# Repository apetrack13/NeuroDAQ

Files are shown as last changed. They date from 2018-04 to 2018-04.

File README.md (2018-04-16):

# NeuroDAQ
<p> The NeuroDAQ is a quality control device for transcranial electrical stimulation (tES) generation devices.
The aim is to improve the outcomes of tES studies by verifying the fidelity of stimulation generation from
tES devices. </p>
<h2>Setting Up the NeuroDAQ</h2>
<p> The NeuroDAQ requires a connection to a local network. </p>

<h3>Setup Wireless Connection</h3>

1.)	Check if micro USB power cable is connected to NeuroDAQ located on the side.

2.)	Remove micro SD card from NeuroDAQ located on the side. 

3.)	Insert micro SD card into adaptor SD card adaptor provided with kit.

4.)	Plug the SD Card adaptor into computer. A new volume should appear in your finder/ file explorer.

5.)	Open the new volume and navigate to the boot directory /Volumes/boot.

6.)	Create a file called wpa_supplicant.conf in this directory and save it.

7.)	Open the file and add the following details:                                                					network={												ssid=”YOUR_NETWORK_NAME”									psk=”YOUR_PASSWORD”									key_mgmt=WPA-PSK

8.)	Eject the SD card and plug it back into the NeuroDAQ.

<h2>Using the NeuroDAQ via Terminal</h2>
<h3>Establish SSH Connection to NeuroDAQ</h3>
<p>
The NeuroDAQ can be controlled via a ssh connection. Once a ssh connection is established, data acquisition can be iniated.
</p>
1.)	First, be sure the micro USB power cable is connected to the NeuroDAQ.

2.)	Open terminal in the applications folder of Mac OS computer.

3.)	Type ssh pi@NeuroDAQ.local and press enter.

4.)	If prompted to answer a yes or no question, type yes and press enter. If not, skip to step 4.

5.)	You will be prompted to enter a password to connect to the device. The password is “GIZMO629” (obviously no quotes).

6.)	You are now connected to the device’s terminal from which you can execute scripts.

<h3>Retrieve Data File</h3>
1.)	In the Mac OS terminal connected to the device, type and enter:					scp pi@NeuroDAQ.local:~/Desktop/DATA_FILE_NAME.csv ~/Desktop		

Replace DATA_FILE_NAME with what you named the data file during data acquisition. 

2.)	The data file will be transferred to the desktop of your Mac OS computer. You now can process this data file with the MATLAB script provided.

<h3>Process Data File with MATLAB</h3>
1.)	Locate the MATLAB script file named “Process_Signal.m”. This script is available at github.com/NeuroModQC-WSU-Design/NeuroDAQ/.

2.)	Place the data file in the same directory as this script.

3.)	Open the script with MATLAB and run.

4.)	You will be prompted to answer questions about the stimulation paradigm recorded. Please, refer to the stimulation paradigm parameters used to record the data file.

5.)	Statistical analysis and graphs of stimulation paradigm will be presented.

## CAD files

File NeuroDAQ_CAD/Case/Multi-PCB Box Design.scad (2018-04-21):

/*//////////////////////////////////////////////////////////////////                
////////////////////////////////////////////////////////////////////                                                                                                           


*/////////////////////////// - Info - //////////////////////////////

// All coordinates are starting as integrated circuit pins.
// From the top view :

//   CoordD           <---       CoordC
//                                 ^
//                                 ^
//                                 ^
//   CoordA           --->       CoordB


////////////////////////////////////////////////////////////////////


////////// -  Box parameters - /////////////

/* [Box dimensions] */
// - Length  
  Length        = 254;       
// - Width
  Width         = 200;                     
// - Height  
  Height        = 100;  
// - Wall thickness  
  Thick         = 2;//[2:5]  
  
/* [Box options] */
// - Filet diameter  
  Filet         = 2;//[0.1:12] 
// - Filet smoothness  
  Resolution    = 50;//[1:100] 
// - Tolerance (Panel/rails gap)
  m             = 0.9;
// - PCB feet (x4) 
  PCBFeet       = 1;// [0:No, 1:Yes]
// - PCB2 feet (x4) 
  PCB2Feet       = 1;// [0:No, 1:Yes] 
// - PCB3 feet (x4) 
  PCB3Feet       = 1;// [0:No, 1:Yes] 
// - PCB4 feet (x4) 
  PCB4Feet       = 1;// [0:No, 1:Yes] 
// - PCB5 feet (x4) 
  PCB5Feet       = 0;// [0:No, 1:Yes]
// - PCB6 feet (x4)
  PCB6Feet       = 1;// [0:No, 1:Yes]  
// - Ventilation Holes
  Vent          = 1;// [0:No, 1:Yes]
// - Holes width (in mm)
  Vent_width    = 1.5;   


  
/* [PCB_Feet - Raspberry Pi] */
//All dimensions are from the center foot axis

// - Low left corner X position
PCBPosX         = 180;
// - Low left corner Y position
PCBPosY         = 84;
// - PCB Length
PCBLength       = 49;
// - PCB Width
PCBWidth        = 58;
// - Feet height
FootHeight      = 10;
// - Foot diameter
FootDia         = 8;
// - Hole diameter
FootHole        = 3;  


/* [PCB2_Feet - Purple PCB] */
//All dimensions are from the center foot axis

// - Low left corner X position
PCB2PosX         = 7;
// - Low left corner Y position
PCB2PosY         = 116;
// - PCB2 Length
PCB2Length       = 63;
// - PCB Width
PCB2Width        = 54;
// - Feet height
Foot2Height      = 10;
// - Foot diameter
Foot2Dia         = 8;
// - Hole diameter
Foot2Hole       = 3; 


/* [PCB3_Feet - Green PCB 1 - Connected to Green PCB 2] */
//All dimensions are from the center foot axis

// - Low left corner X position
PCB3PosX         = 120;
// - Low left corner Y position
PCB3PosY         = 116;
// - PCB2 Length
PCB3Length       = 35;
// - PCB Width
PCB3Width        = 55;
// - Feet height
Foot3Height      = 10;
// - Foot diameter
Foot3Dia         = 8;
// - Hole diameter
Foot3Hole       = 3;

/* [PCB4_Feet - Green PCB 2 - Connected to Green PCB 1] */
//All dimensions are from the center foot axis

// - Low left corner X position
PCB4PosX         = 120;
// - Low left corner Y position
PCB4PosY         = 10;
// - PCB2 Length
PCB4Length       = 35;
// - PCB Width
PCB4Width        = 55;
// - Feet height
Foot4Height      = 10;
// - Foot diameter
Foot4Dia         = 8;
// - Hole diameter
Foot4Hole       = 3;

/* [PCB5_Feet - Green PCB 3] */
//All dimensions are from the center foot axis

// - Low left corner X position
PCB5PosX         = 60;
// - Low left corner Y position
PCB5PosY         = 10;
// - PCB2 Length
PCB5Length       = 35;
// - PCB Width
PCB5Width        = 55;
// - Feet height
Foot5Height      = 10;
// - Foot diameter
Foot5Dia         = 8;
// - Hole diameter
Foot5Hole       = 3;

/* [PCB6_Feet - Green PCB 1 - Connected to Green PCB 2] */
//All dimensions are from the center foot axis

// - Low left corner X position
PCB6PosX         = 5;
// - Low left corner Y position
PCB6PosY         = 10;
// - PCB2 Length
PCB6Length       = 35;
// - PCB Width
PCB6Width        = 55;
// - Feet height
Foot6Height      = 10;
// - Foot diameter
Foot6Dia         = 8;
// - Hole diameter
Foot6Hole       = 3;
  

/* [STL element to export] */
// - Top shell
TShell          = 0;// [0:No, 1:Yes]
// - Bottom shell
BShell          = 1;// [0:No, 1:Yes]
// - Front panel
FPanL           = 1;// [0:No, 1:Yes]
// - Back panel  
BPanL           = 1;// [0:No, 1:Yes]


  
/* [Hidden] */
// - Shell color  
Couleur1        = "Orange";       
// - Panels color    
Couleur2        = "OrangeRed";    
// Thick X 2 - make thicker; if it is a vent, want to make sure they go through shell
Dec_Thick       = Vent ? Thick*2 : Thick; 
// - Depth 
Dec_size        = Vent ? Thick*2 : 0.8;





/////////// - Generic rounded box - //////////

module RoundBox($a=Length, $b=Width, $c=Height){// Cube bords arrondis
                    $fn=Resolution;            
                    translate([0,Filet,Filet]){  
                    minkowski (){                                              
                        cube ([$a-(Length/2),$b-(2*Filet),$c-(2*Filet)], center = false);
                        rotate([0,90,0]){    
                        cylinder(r=Filet,h=Length/2, center = false);
                            } 
                        }
                    }
                }// End of RoundBox Module

      
////////////////////////////////// - Module Shell - //////////////////////////////////         

module Coque(){//Shell  
    Thick = Thick*2;  
    difference(){    
        difference(){//sides decoration
            union(){    
                     difference() {//Substraction Fileted box
                      
                        difference(){//Median cube slicer
                            union() {//union               
                            difference(){//Coque    
                                RoundBox();
                                translate([Thick/2,Thick/2,Thick/2]){     
                                        RoundBox($a=Length-Thick, $b=Width-Thick, $c=Height-Thick);
                                        }
                                        }//Fin diff Coque                            
                                difference(){//larger Rails        
                                     translate([Thick+m,Thick/2,Thick/2]){// Rails
                                          RoundBox($a=Length-((2*Thick)+(2*m)), $b=Width-Thick, $c=Height-(Thick*2));
                                                          }//fin Rails
                                     translate([((Thick+m/2)*1.55),Thick/2,Thick/2+0.1]){ // +0.1 added to avoid the artefact
                                          RoundBox($a=Length-((Thick*3)+2*m), $b=Width-Thick, $c=Height-Thick);
                                                    }           
                                                }//Fin largeur Rails
                                    }//Fin union                                   
                               translate([-Thick,-Thick,Height/2]){// Cube à soustraire
                                    cube ([Length+100, Width+100, Height], center=false);
                                            }                                            
                                      }//End Median cube slicer
                               translate([-Thick/2,Thick,Thick]){ 
                                    RoundBox($a=Length+Thick, $b=Width-Thick*2, $c=Height-Thick);       
                                    }                          
                                }                                          


                difference(){// wall fixation box legs
                    union(){
                        translate([3*Thick +5,Thick,Height/2]){
                            rotate([90,0,0]){
                                    $fn=6;
                                    cylinder(d=16,Thick/2);
                                    }   
                            }
                            
                       translate([Length-((3*Thick)+5),Thick,Height/2]){
                            rotate([90,0,0]){
                                    $fn=6;
                                    cylinder(d=16,Thick/2);
                                    }   
                            }

                        }
                            translate([4,Thick+Filet,Height/2-57]){   
                             rotate([45,0,0]){
                                   cube([Length,40,40]);    
                                  }
                           }
                           translate([0,-(Thick*1.46),Height/2]){
                                cube([Length,Thick*2,10]);
                           }
                    } //Fin fixation box legs
            }

        union(){// outbox sides decorations
            
            for(i=[0:Thick:Length/4]){
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

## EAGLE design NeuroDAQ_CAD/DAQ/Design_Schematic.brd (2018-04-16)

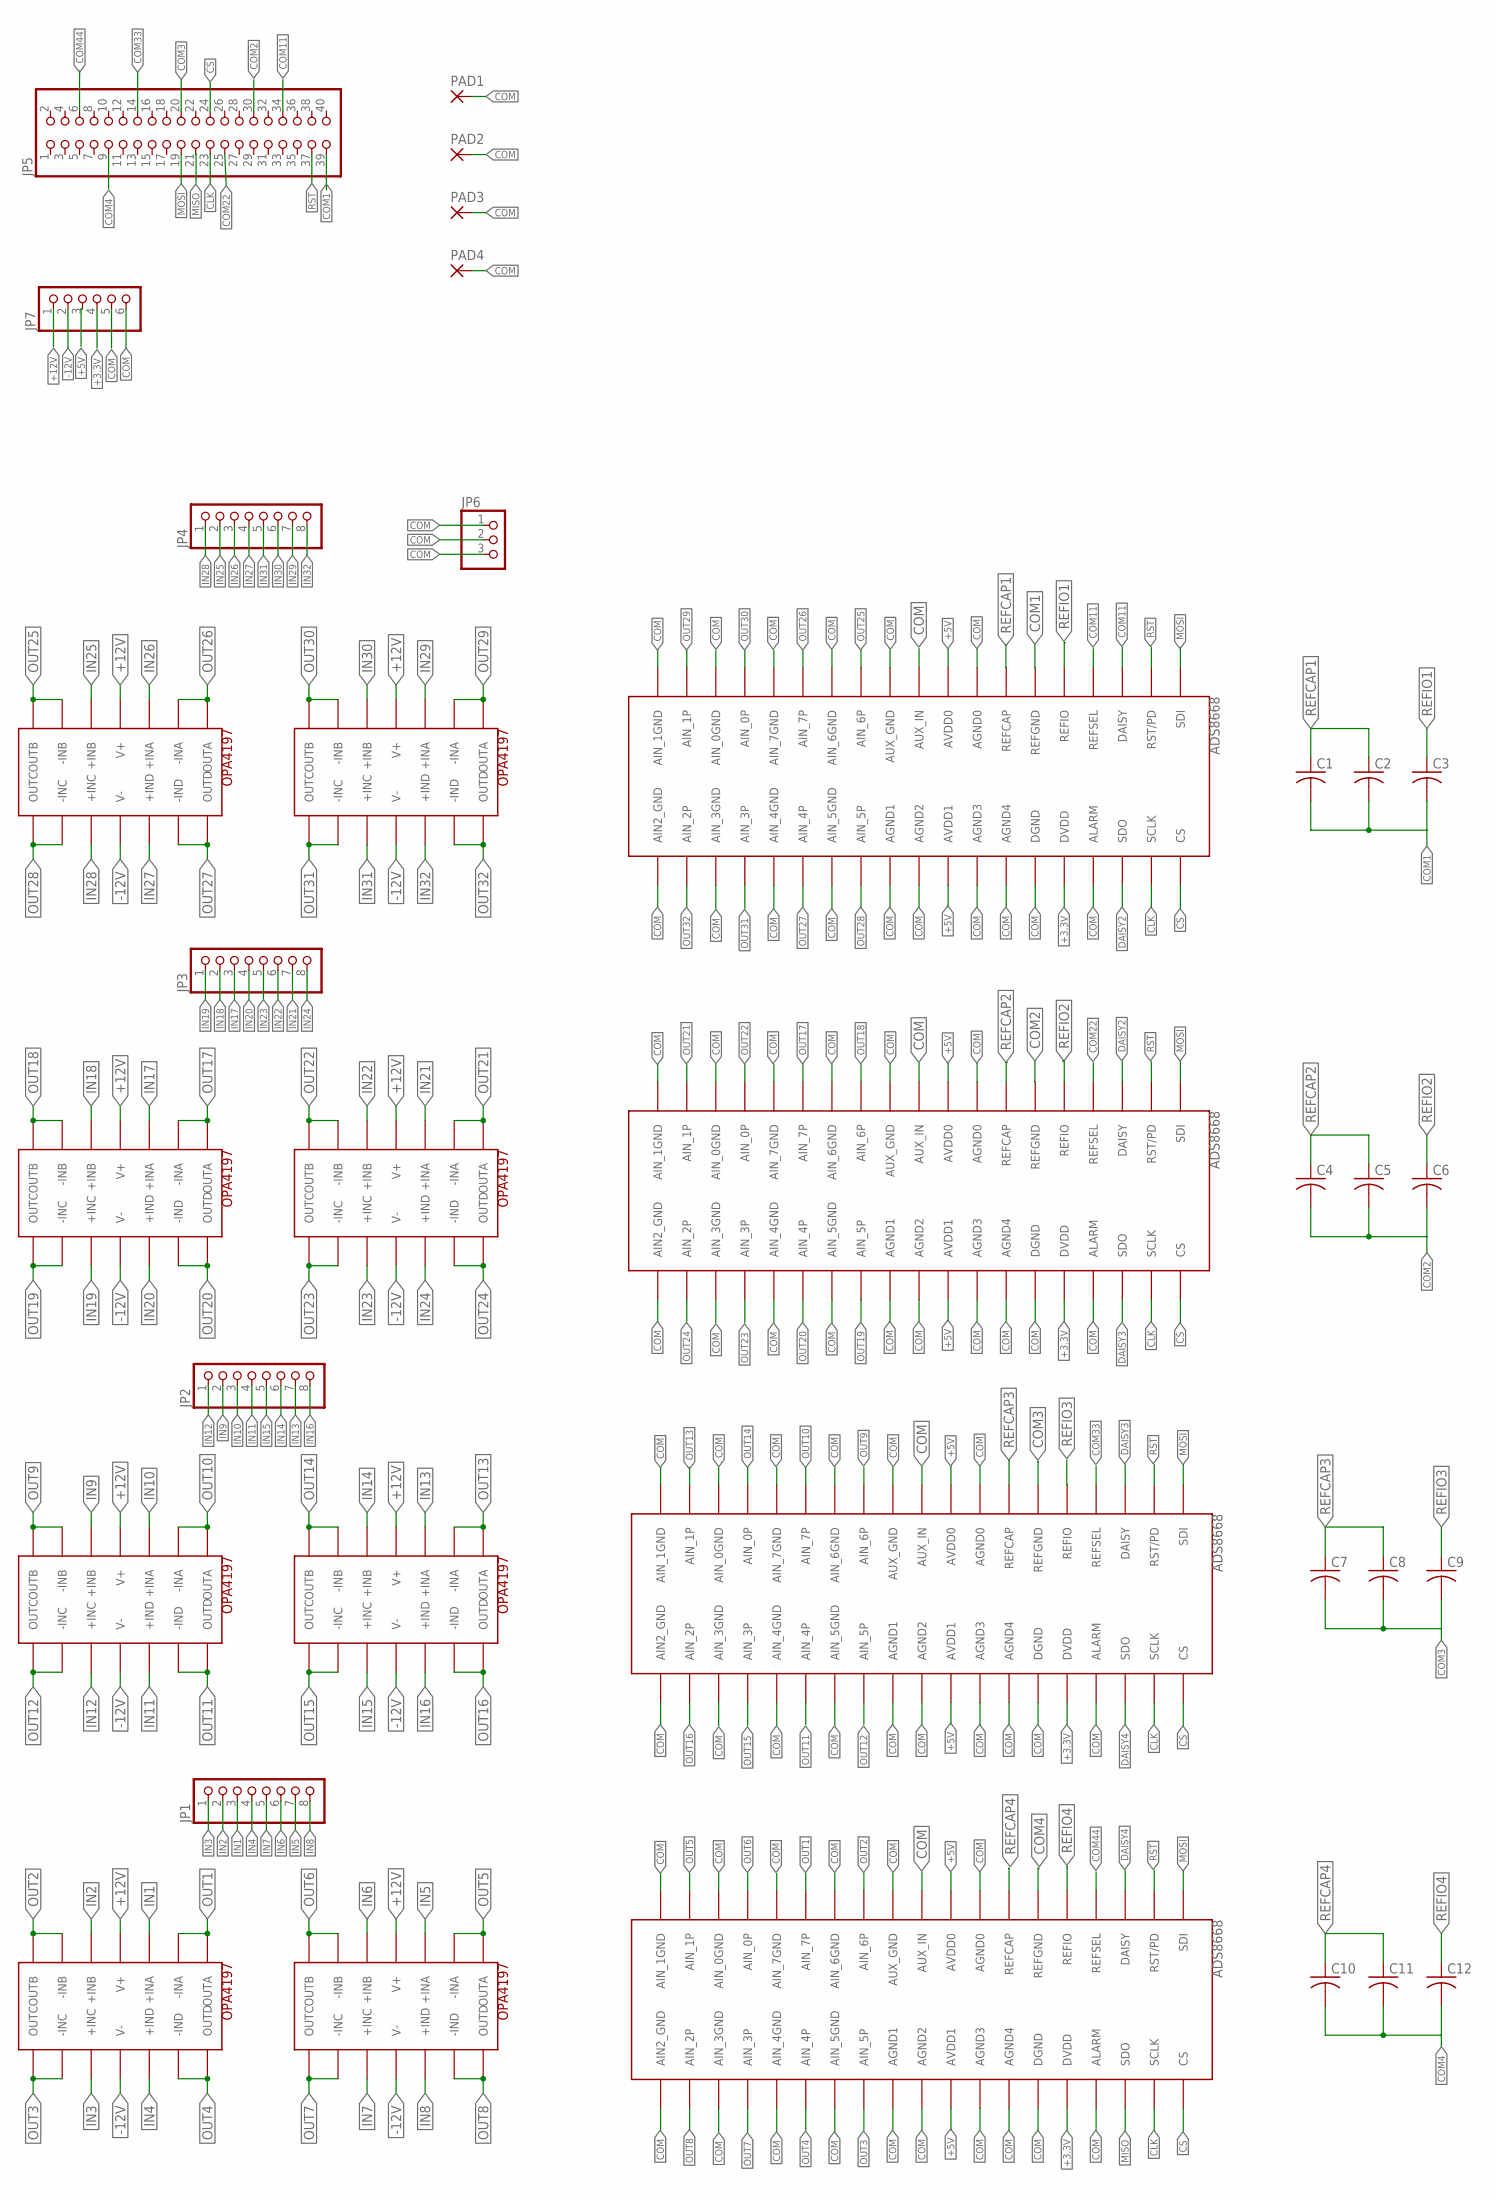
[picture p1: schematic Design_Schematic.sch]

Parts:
ADC1, ADC2, ADC3, ADC4: ADS8668
C1, C2, C3, C4, C5, C6, C7, C8, C9, C10, C11, C12: C-US025-030X050; C025-030X050
JP1, JP2, JP3, JP4: PINHD-1X8CLEANBIG; 1X08-CLEANBIG
JP5: PINHD-2X20; 2X20
JP6: PINHD-1X3; 1X03
JP7: PINHD-1X6; 1X06
PAD1, PAD2, PAD3, PAD4: 3,17/1,3
U$1, U$2, U$3, U$4, U$5, U$6, U$7, U$8: OPA4197

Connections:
+3.3V: ADC1.DVDD, ADC2.DVDD, ADC3.DVDD, ADC4.DVDD, JP7.4
+5V: ADC1.AVDD0, ADC1.AVDD1, ADC2.AVDD0, ADC2.AVDD1, ADC3.AVDD0, ADC3.AVDD1, ADC4.AVDD0, ADC4.AVDD1, JP7.3
+12V: JP7.1, U$1.V+, U$2.V+, U$3.V+, U$4.V+, U$5.V+, U$6.V+, U$7.V+, U$8.V+
-12V: JP7.2, U$1.V-, U$2.V-, U$3.V-, U$4.V-, U$5.V-, U$6.V-, U$7.V-, U$8.V-
CLK: ADC1.SCLK, ADC2.SCLK, ADC3.SCLK, ADC4.SCLK, JP5.23
COM: ADC1.AGND0, ADC1.AGND1, ADC1.AGND2, ADC1.AGND3, ADC1.AGND4, ADC1.AIN2_GND, ADC1.AIN6_GND (AIN_6GND), ADC1.AIN_0GND, ADC1.AIN_1GND, ADC1.AIN_3GND, ADC1.AIN_4GND, ADC1.AIN_5GND, ADC1.AIN_7GND, ADC1.ALARM, ADC1.AUX_GND, ADC1.AUX_IN, ADC1.DGND, ADC2.AGND0, ADC2.AGND1, ADC2.AGND2, ADC2.AGND3, ADC2.AGND4, ADC2.AIN2_GND, ADC2.AIN6_GND (AIN_6GND), ADC2.AIN_0GND, ADC2.AIN_1GND, ADC2.AIN_3GND, ADC2.AIN_4GND, ADC2.AIN_5GND, ADC2.AIN_7GND, ADC2.ALARM, ADC2.AUX_GND, ADC2.AUX_IN, ADC2.DGND, ADC3.AGND0, ADC3.AGND1, ADC3.AGND2, ADC3.AGND3, ADC3.AGND4, ADC3.AIN2_GND, ADC3.AIN6_GND (AIN_6GND), ADC3.AIN_0GND, ADC3.AIN_1GND, ADC3.AIN_3GND, ADC3.AIN_4GND, ADC3.AIN_5GND, ADC3.AIN_7GND, ADC3.ALARM, ADC3.AUX_GND, ADC3.AUX_IN, ADC3.DGND, ADC4.AGND0, ADC4.AGND1, ADC4.AGND2, ADC4.AGND3, ADC4.AGND4, ADC4.AIN2_GND, ADC4.AIN6_GND (AIN_6GND), ADC4.AIN_0GND, ADC4.AIN_1GND, ADC4.AIN_3GND, ADC4.AIN_4GND, ADC4.AIN_5GND, ADC4.AIN_7GND, ADC4.ALARM, ADC4.AUX_GND, ADC4.AUX_IN, ADC4.DGND, JP6.1, JP6.2, JP6.3, JP7.5, JP7.6, PAD1.1, PAD2.1, PAD3.1, PAD4.1
COM1: ADC4.REFGND, C1.2, C2.2, C3.2, JP5.39
COM2: ADC1.REFGND, C4.2, C5.2, C6.2, JP5.30
COM3: ADC2.REFGND, C7.2, C8.2, C9.2, JP5.20
COM4: ADC3.REFGND, C10.2, C11.2, C12.2, JP5.9
COM11: ADC4.DAISY, ADC4.REFSEL, JP5.34
COM22: ADC1.REFSEL, JP5.25
COM33: ADC2.REFSEL, JP5.14
COM44: ADC3.REFSEL, JP5.6
CS: ADC1.CS, ADC2.CS, ADC3.CS, ADC4.CS, JP5.24
DAISY2: ADC1.DAISY, ADC4.SDO
DAISY3: ADC1.SDO, ADC2.DAISY
DAISY4: ADC2.SDO, ADC3.DAISY
IN1: JP1.3, U$5.+INA
IN2: JP1.2, U$5.+INB
IN3: JP1.1, U$5.+INC
IN4: JP1.4, U$5.+IND
IN5: JP1.7, U$1.+INA
IN6: JP1.6, U$1.+INB
IN7: JP1.5, U$1.+INC
IN8: JP1.8, U$1.+IND
IN9: JP2.2, U$2.+INB
IN10: JP2.3, U$2.+INA
IN11: JP2.4, U$2.+IND
IN12: JP2.1, U$2.+INC
IN13: JP2.7, U$3.+INA
IN14: JP2.6, U$3.+INB
IN15: JP2.5, U$3.+INC
IN16: JP2.8, U$3.+IND
IN17: JP3.3, U$4.+INA
IN18: JP3.2, U$4.+INB
IN19: JP3.1, U$4.+INC
IN20: JP3.4, U$4.+IND
IN21: JP3.7, U$6.+INA
IN22: JP3.6, U$6.+INB
IN23: JP3.5, U$6.+INC
IN24: JP3.8, U$6.+IND
IN25: JP4.2, U$7.+INB
IN26: JP4.3, U$7.+INA
IN27: JP4.4, U$7.+IND
IN28: JP4.1, U$7.+INC
IN29: JP4.7, U$8.+INA
IN30: JP4.6, U$8.+INB
IN31: JP4.5, U$8.+INC
IN32: JP4.8, U$8.+IND
MISO: ADC3.SDO, JP5.21
MOSI: ADC1.SDI, ADC2.SDI, ADC3.SDI, ADC4.SDI, JP5.19
OUT1: ADC3.AIN_7P, U$5.-INA, U$5.OUTA
OUT2: ADC3.AIN_6P, U$5.-INB, U$5.OUTB
OUT3: ADC3.AIN_5P, U$5.-INC, U$5.OUTC
OUT4: ADC3.AIN_4P, U$5.-IND, U$5.OUTD
OUT5: ADC3.AIN_1P, U$1.-INA, U$1.OUTA
OUT6: ADC3.AIN_0P, U$1.-INB, U$1.OUTB
OUT7: ADC3.AIN_3P, U$1.-INC, U$1.OUTC
OUT8: ADC3.AIN_2P, U$1.-IND, U$1.OUTD
OUT9: ADC2.AIN_6P, U$2.-INB, U$2.OUTB
OUT10: ADC2.AIN_7P, U$2.-INA, U$2.OUTA
OUT11: ADC2.AIN_4P, U$2.-IND, U$2.OUTD
OUT12: ADC2.AIN_5P, U$2.-INC, U$2.OUTC
OUT13: ADC2.AIN_1P, U$3.-INA, U$3.OUTA
OUT14: ADC2.AIN_0P, U$3.-INB, U$3.OUTB
OUT15: ADC2.AIN_3P, U$3.-INC, U$3.OUTC
OUT16: ADC2.AIN_2P, U$3.-IND, U$3.OUTD
OUT17: ADC1.AIN_7P, U$4.-INA, U$4.OUTA
OUT18: ADC1.AIN_6P, U$4.-INB, U$4.OUTB
OUT19: ADC1.AIN_5P, U$4.-INC, U$4.OUTC
OUT20: ADC1.AIN_4P, U$4.-IND, U$4.OUTD
OUT21: ADC1.AIN_1P, U$6.-INA, U$6.OUTA
OUT22: ADC1.AIN_0P, U$6.-INB, U$6.OUTB
OUT23: ADC1.AIN_3P, U$6.-INC, U$6.OUTC
OUT24: ADC1.AIN_2P, U$6.-IND, U$6.OUTD
OUT25: ADC4.AIN_6P, U$7.-INB, U$7.OUTB
OUT26: ADC4.AIN_7P, U$7.-INA, U$7.OUTA
OUT27: ADC4.AIN_4P, U$7.-IND, U$7.OUTD
OUT28: ADC4.AIN_5P, U$7.-INC, U$7.OUTC
OUT29: ADC4.AIN_1P, U$8.-INA, U$8.OUTA
OUT30: ADC4.AIN_0P, U$8.-INB, U$8.OUTB
OUT31: ADC4.AIN_3P, U$8.-INC, U$8.OUTC
OUT32: ADC4.AIN_2P, U$8.-IND, U$8.OUTD
REFCAP1: ADC4.REFCAP, C1.1, C2.1
REFCAP2: ADC1.REFCAP, C4.1, C5.1
REFCAP3: ADC2.REFCAP, C7.1, C8.1
REFCAP4: ADC3.REFCAP, C10.1, C11.1
REFIO1: ADC4.REFIO, C3.1
REFIO2: ADC1.REFIO, C6.1
REFIO3: ADC2.REFIO, C9.1
REFIO4: ADC3.REFIO, C12.1
RST: ADC1.RST/PD, ADC2.RST/PD, ADC3.RST/PD, ADC4.RST/PD, JP5.37

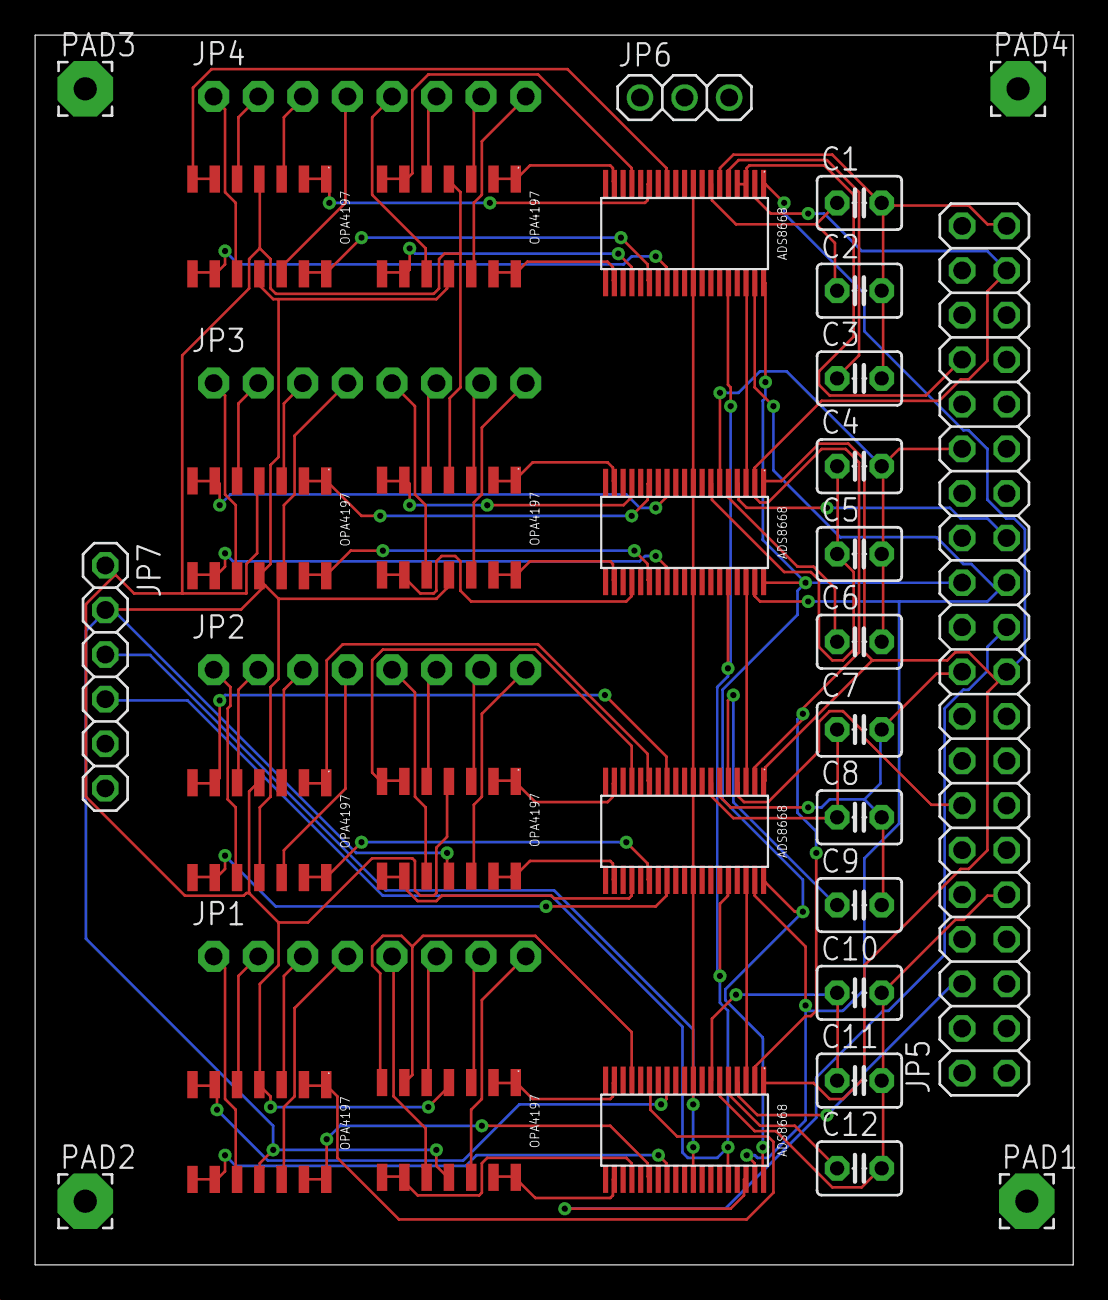
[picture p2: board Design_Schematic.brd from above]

Board: 2 copper layers, 59.1 x 70.1 mm, 35 parts (0 on the bottom side), 93 nets.

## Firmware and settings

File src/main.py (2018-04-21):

import dataAcq
import cmd

def main():
    fileName = input("Enter the name of file in double quotes: ")
    fileName = fileName + ".csv"
    duration = input("Enter duration of test in seconds: ")
    numChannels = input("Enter active number of channels: ")
    
    dataAcq.beginAcq(numChannels, duration, fileName)

main()

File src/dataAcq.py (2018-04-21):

import time
import Adafruit_GPIO.SPI as SPI
import Adafruit_MCP3008
import RPi.GPIO as gpio


def beginAcq(numChannels, duration, fileName):
    SPI_PORT = 0
    SPI_DEVICE = 0
    mcp = Adafruit_MCP3008.MCP3008(spi=SPI.SpiDev(SPI_PORT, SPI_DEVICE))

    gpio.setmode(gpio.BCM)
    gpio.setup(26, gpio.OUT)
    gpio.output(26, gpio.LOW)
    gpio.output(26, gpio.HIGH)

    t1 = time.time() + duration
    # print(t1)
    with open(fileName, 'w+') as f:
        f.write('')

    print('Reading ADS8668 values, press Ctrl-C to quit...')

    # Main Loop
    while (time.time() < t1):
        values = []
        tempTime = [0]
        tempTime[0] = round(time.time() - t1 + duration, 4)

        if numChannels == 1:
           # Channel 1
            mcp.read_all_ch(0xC0)
            values0 = mcp.read_all_ch(0xC0)
            values0[0] = ((float(values0[0]) - 2046) / 197)   # ADC 1
            values0[1] = ((float(values0[1]) - 2046) / 197)   # ADC 2

            # Append samples to array
            values.extend(values0[0:2])
            values.extend(tempTime)

        elif (numChannels == 2):
            # Channel 1
            mcp.read_all_ch(0xC0)
            values0 = mcp.read_all_ch(0xC0)
            values0[0] = ((float(values0[0]) - 2046) / 197)  # ADC 1
            values0[1] = ((float(values0[1]) - 2046) / 197)  # ADC 2
            # Channel 2
            values0[2] = ((float(values0[2]) - 2046) / 197)  # ADC 3
            values0[3] = ((float(values0[3]) - 1535) / 195)  # ADC 4

            # Append samples to array
            values.extend(values0)
            values.extend(tempTime)

        elif numChannels == 3:
            # Channel 1
            mcp.read_all_ch(0xC0)
            values0 = mcp.read_all_ch(0xC0)
            values0[0] = ((float(values0[0]) - 2046) / 197)  # ADC 1
            values0[1] = ((float(values0[1]) - 2046) / 197)  # ADC 2
            # Channel 2
            values0[2] = ((float(values0[2]) - 2046) / 197)  # ADC 3
            values0[3] = ((float(values0[3]) - 1535) / 195)  # ADC 4
            # Channel 3
            mcp.read_all_ch(0xC4)
            values1 = mcp.read_all_ch(0xC4)
            values1[0] = ((float(values1[0]) - 2046) / 200)
            values1[1] = ((float(values1[1]) - 2046) / 200)
            # Append Samples to array
            values.extend(values0)
            values.extend(values1[0:2])
            values.extend(tempTime)

        elif numChannels == 4:
            # Channel 1
            mcp.read_all_ch(0xC0)
            values0 = mcp.read_all_ch(0xC0)
            values0[0] = ((float(values0[0]) - 2046) / 197)  # ADC 1
            values0[1] = ((float(values0[1]) - 2046) / 197)  # ADC 2
            # Channel 2
            values0[2] = ((float(values0[2]) - 2046) / 197)  # ADC 3
            values0[3] = ((float(values0[3]) - 1535) / 195)  # ADC 4
            # Channel 3
            mcp.read_all_ch(0xC4)
            values1 = mcp.read_all_ch(0xC4)
            values1[0] = ((float(values1[0]) - 2046) / 200)
            values1[1] = ((float(values1[1]) - 2046) / 200)
            # Channel 4
            values1[2] = ((float(values1[2]) - 1535) / 200)
            values1[3] = ((float(values1[3]) - 1535) / 200)
            # Append Samples to array
            values.extend(values0)
            values.extend(values1)
            values.extend(tempTime)

        elif numChannels == 5:
            # Channel 1
            mcp.read_all_ch(0xC0)
            values0 = mcp.read_all_ch(0xC0)
            values0[0] = ((float(values0[0]) - 2046) / 197)  # ADC 1
            values0[1] = ((float(values0[1]) - 2046) / 197)  # ADC 2
            # Channel 2
            values0[2] = ((float(values0[2]) - 2046) / 197)  # ADC 3
            values0[3] = ((float(values0[3]) - 1535) / 195)  # ADC 4
            # Channel 3
            mcp.read_all_ch(0xC4)
            values1 = mcp.read_all_ch(0xC4)
            values1[0] = ((float(values1[0]) - 2046) / 200)
            values1[1] = ((float(values1[1]) - 2046) / 200)
            # Channel 4
            values1[2] = ((float(values1[2]) - 1535) / 200)
            values1[3] = ((float(values1[3]) - 1535) / 200)
            # Channel 5
            mcp.read_all_ch(0xC8)
            values2 = mcp.read_all_ch(0xC4)
            values2[0] = ((float(values2[0]) - 2046) / 200)
            values2[1] = ((float(values2[1]) - 2046) / 200)
            # Append Samples to array
            values.extend(values0)
            values.extend(values1)
            values.extend(values2[0:2])
            values.extend(tempTime)

        elif numChannels == 6:
            mcp.read_all_ch(0xC0)
            values0 = mcp.read_all_ch(0xC0)
            # Channel 1
            values0[0] = ((float(values0[0]) - 2046) / 197)  # ADC 1
            values0[1] = ((float(values0[1]) - 2046) / 197)  # ADC 2
            # Channel 2
            values0[2] = ((float(values0[2]) - 2046) / 197)  # ADC 3
            values0[3] = ((float(values0[3]) - 1535) / 195)  # ADC 4
            mcp.read_all_ch(0xC4)
            values1 = mcp.read_all_ch(0xC4)
            # Channel 3
            values1[0] = ((float(values1[0]) - 2046) / 200)
            values1[1] = ((float(values1[1]) - 2046) / 200)
            # Channel 4
            values1[2] = ((float(values1[2]) - 1535) / 200)
            values1[3] = ((float(values1[3]) - 1535) / 200)
            mcp.read_all_ch(0xC8)
            values2 = mcp.read_all_ch(0xC4)
            # Channel 5
            values2[0] = ((float(values2[0]) - 2046) / 200)
            values2[1] = ((float(values2[1]) - 2046) / 200)
            # Channel 6
            values2[2] = ((float(values2[2]) - 1535) / 200)
            values2[3] = ((float(values2[3]) - 1535) / 200)
            # Append Samples to array
            values.extend(values0)
            values.extend(values1)
            values.extend(values2)
            values.extend(tempTime)
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

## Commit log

2018-04-16 Initial Commit - Added Base Files for NeuroDAQ
    [data.csv]
2018-04-16 Added Eagle CAD design of NeuroDAQ.
    [Design_Schematic.brd, Design_Schematic.sch, data.csv]
2018-04-16 Fixed directory.
    [Design_Schematic.brd, Design_Schematic.sch]
2018-04-21 Added case CAD drawing.
    [Design_Schematic.brd, Design_Schematic.sch, Multi-PCB Box Design.scad]
2018-04-21 Fixed clock rate in libraries and file writing.
    [data.csv]
